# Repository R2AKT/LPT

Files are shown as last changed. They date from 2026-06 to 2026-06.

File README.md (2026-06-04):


License addendum - https://github.com/R2AKT/LPT/blob/main/Addendum.txt

# LPT
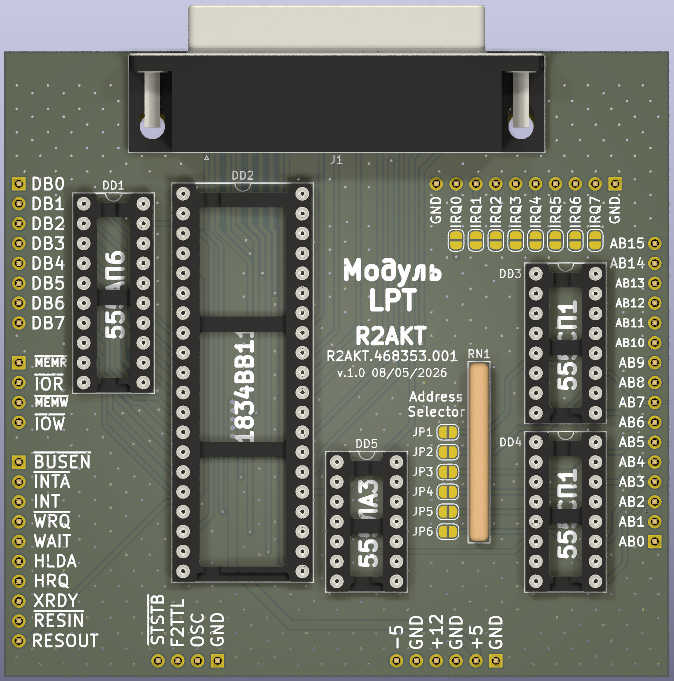
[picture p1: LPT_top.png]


LPT (Centrinics) module. For Mega-80 (Mega-580) DIY 8-bit micro-computer - https://github.com/R2AKT/Mega-80.

Based on 82C11 (1834VV11).

Status: In production. Not tested.

Модуль LPT (Centrinics). Для самодельной 8-битной микро-ЭВМ - https://github.com/R2AKT/Mega-80.

На основе 1834ВВ11 (82C11).

Статус: Изготовливается. Не тестировалась.

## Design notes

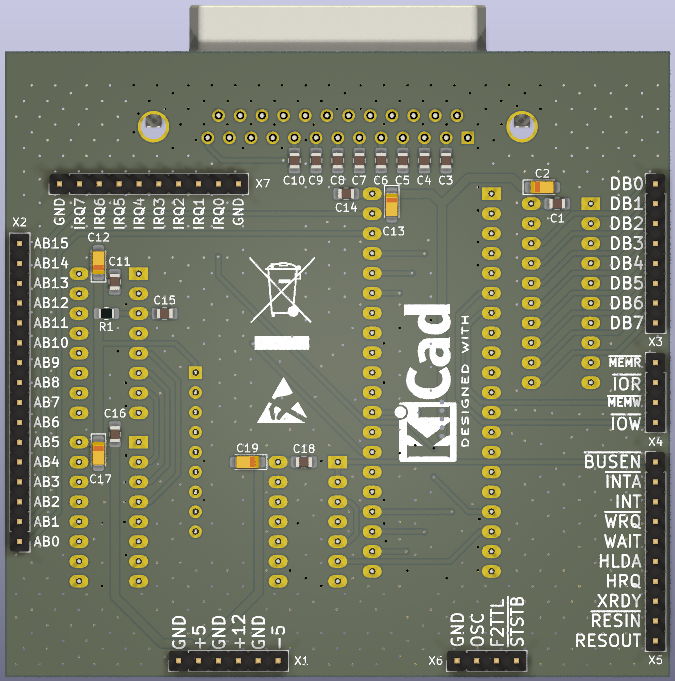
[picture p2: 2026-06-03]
LPT_btn.png

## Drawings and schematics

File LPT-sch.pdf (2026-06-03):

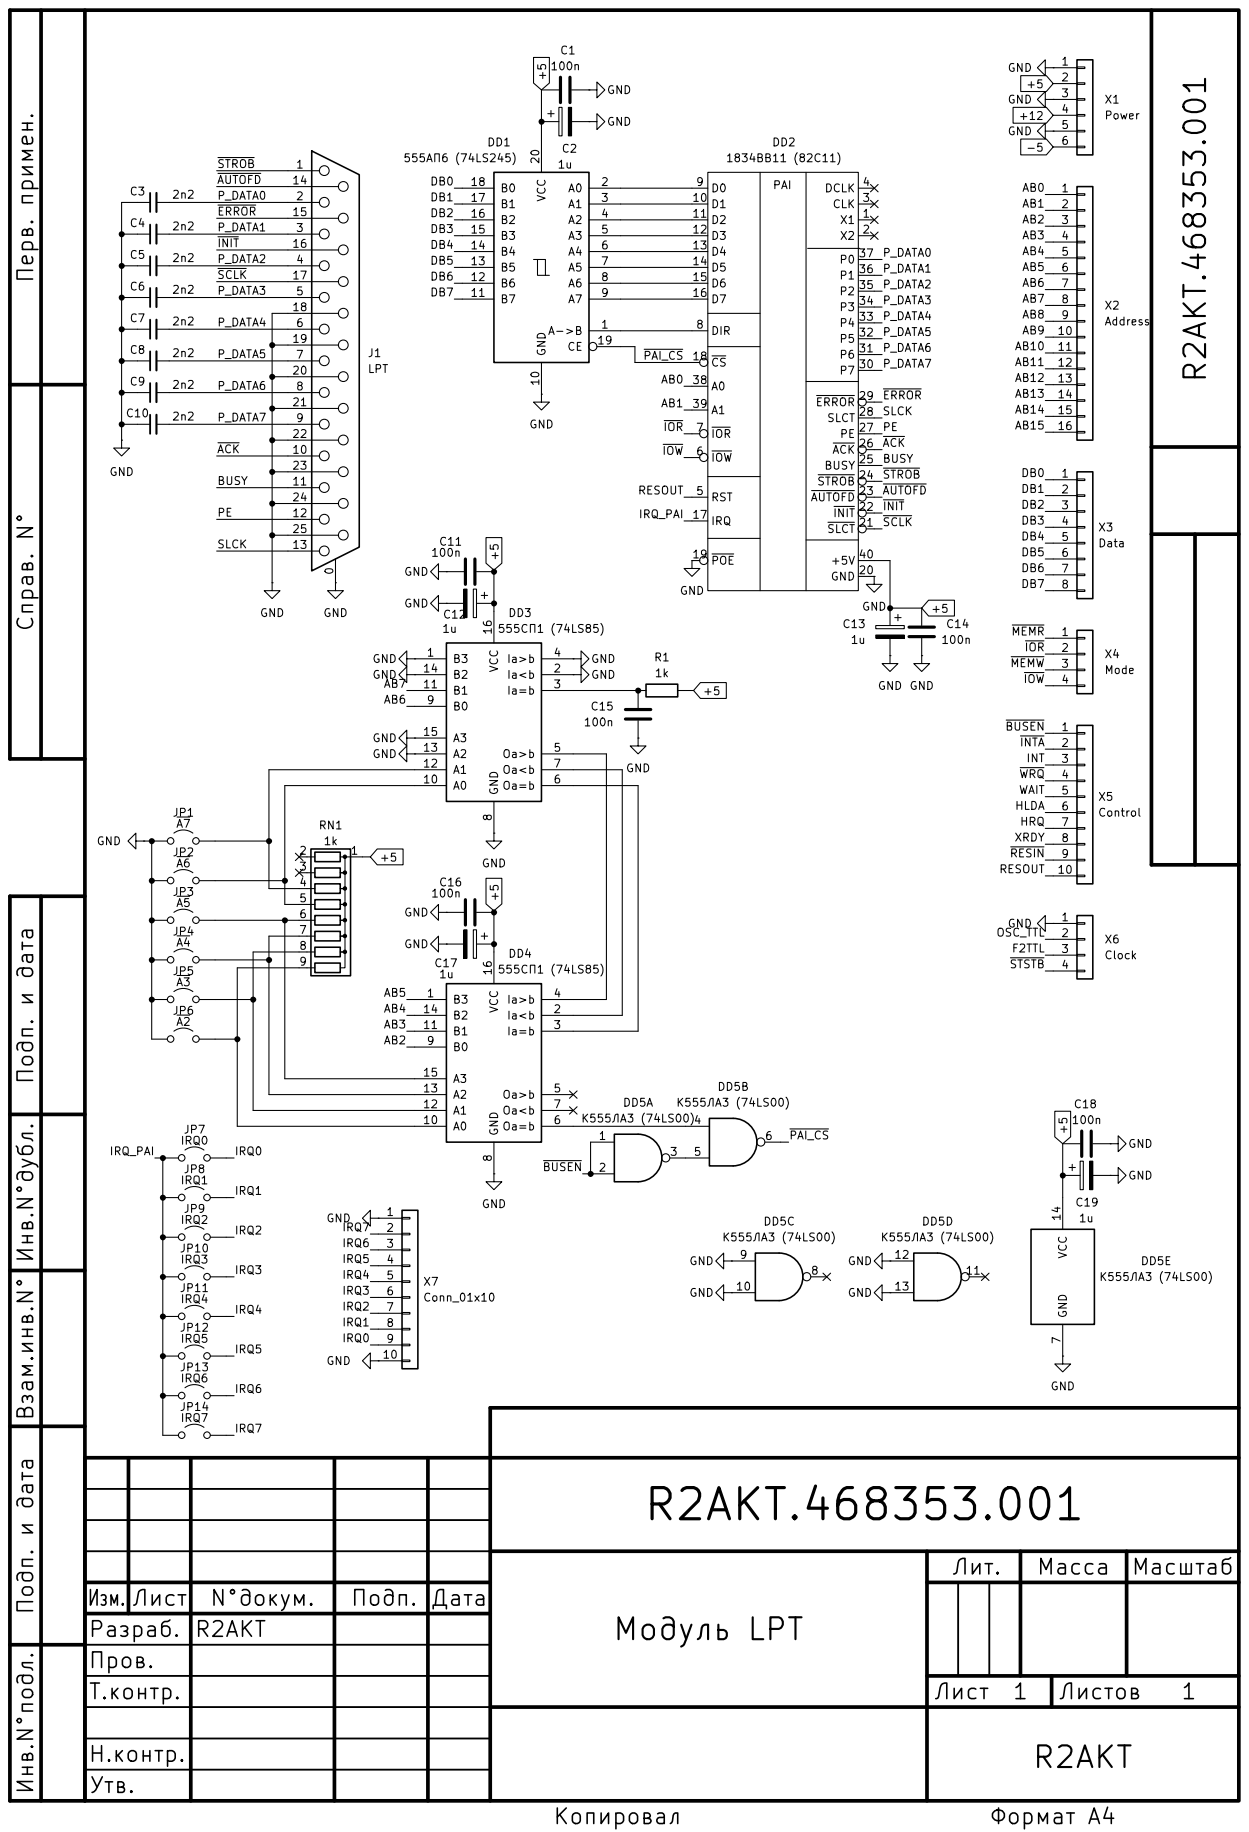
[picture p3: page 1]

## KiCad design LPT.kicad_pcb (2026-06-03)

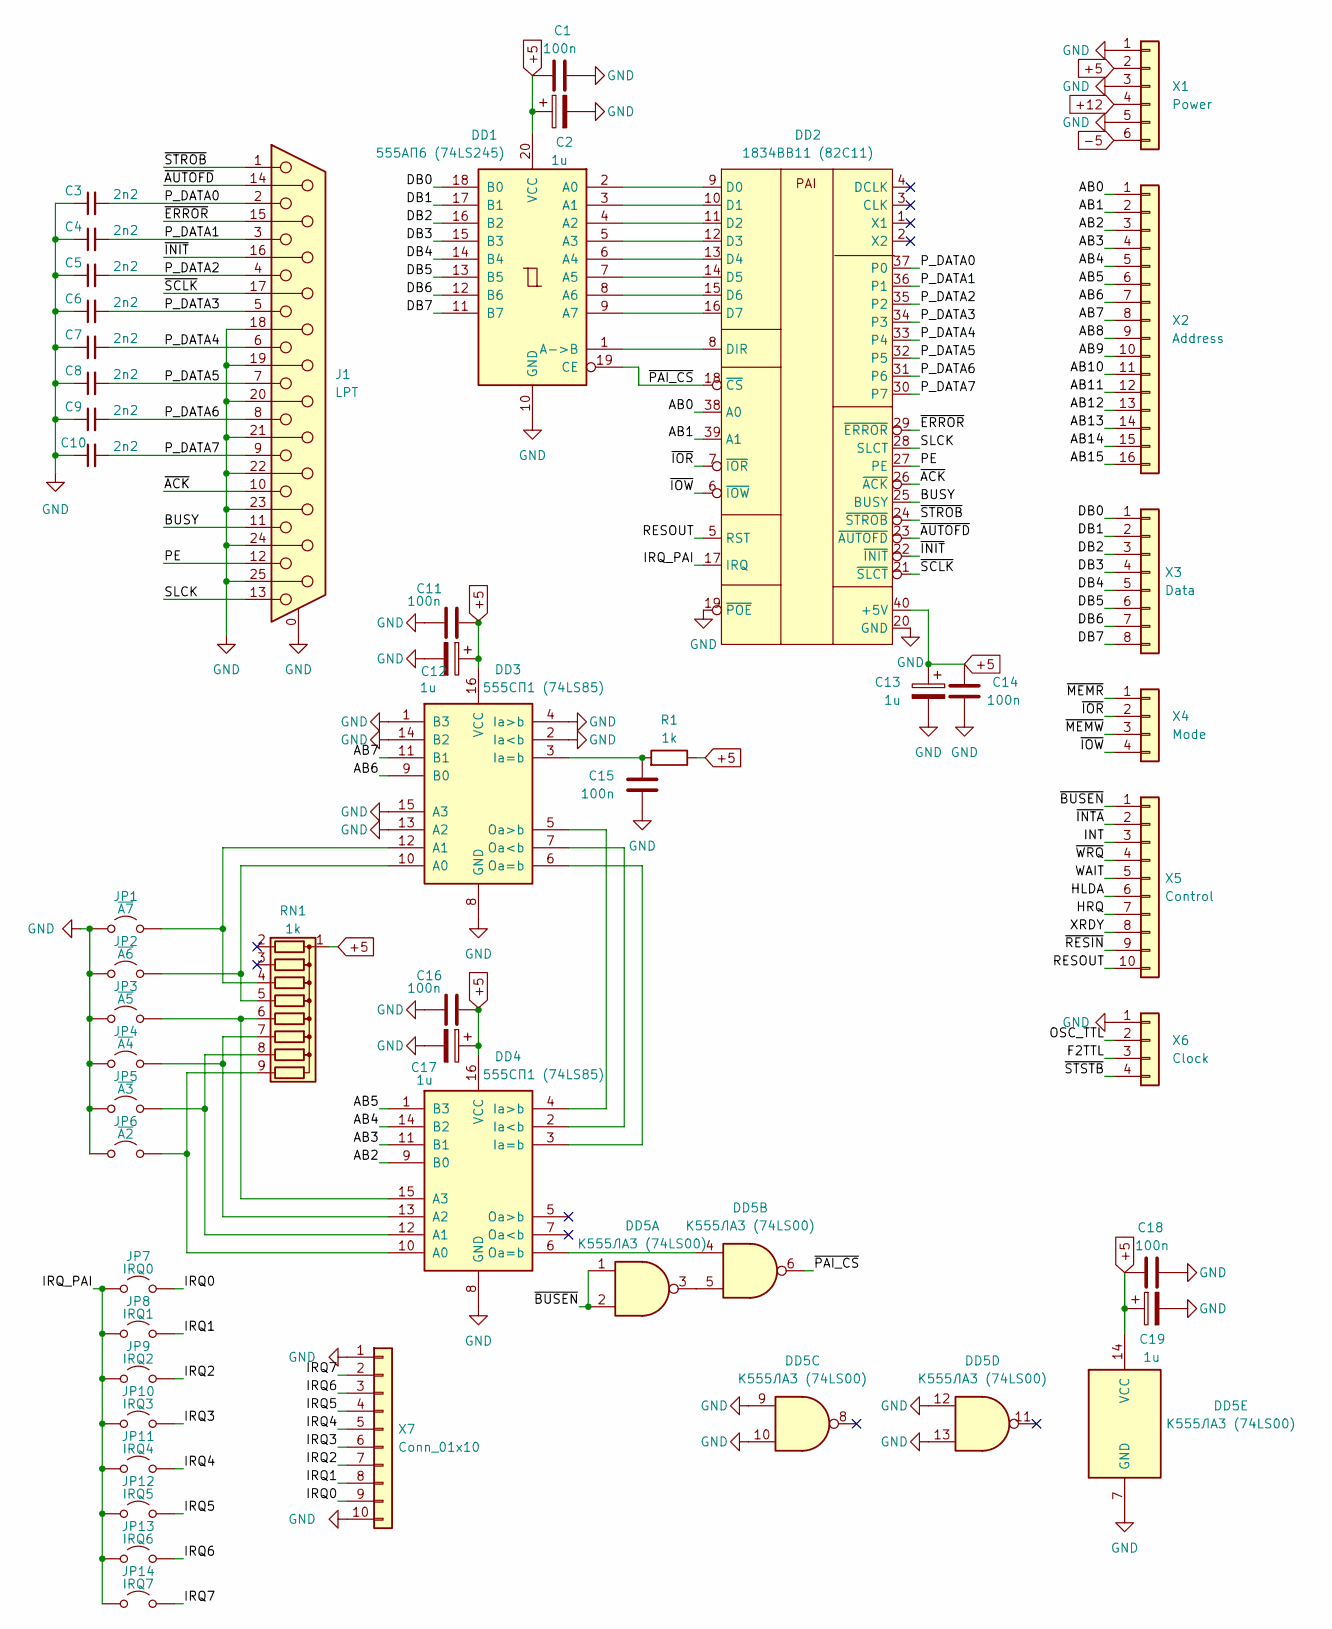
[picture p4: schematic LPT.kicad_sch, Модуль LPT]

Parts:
C1, C11, C14, C15, C16, C18: 100n; C_0805_2012Metric_Pad1.18x1.45mm_HandSolder
C2, C12, C13, C17, C19: 1u; CP_EIA-3216-18_Kemet-A_Pad1.58x1.35mm_HandSolder
C3, C4, C5, C6, C7, C8, C9, C10: 2n2; C_0805_2012Metric_Pad1.18x1.45mm_HandSolder
DD1: 555АП6 (74LS245); DIP-20_W7.62mm_Socket_LongPads
DD2: 1834ВВ11 (82C11); DIP-40_W15.24mm_Socket_LongPads
DD3, DD4: 555СП1 (74LS85); DIP-16_W7.62mm_Socket_LongPads
DD5: К555ЛА3 (74LS00); DIP-14_W7.62mm_Socket_LongPads
J1: LPT; DSUB-25_Female_Horizontal_P2.77x2.84mm_EdgePinOffset7.70mm_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
JP1: ~{A7}; SolderJumper-2_P1.3mm_Open_RoundedPad1.0x1.5mm
JP2: ~{A6}; SolderJumper-2_P1.3mm_Open_RoundedPad1.0x1.5mm
JP3: ~{A5}; SolderJumper-2_P1.3mm_Open_RoundedPad1.0x1.5mm
JP4: ~{A4}; SolderJumper-2_P1.3mm_Open_RoundedPad1.0x1.5mm
JP5: ~{A3}; SolderJumper-2_P1.3mm_Open_RoundedPad1.0x1.5mm
JP6: ~{A2}; SolderJumper-2_P1.3mm_Open_RoundedPad1.0x1.5mm
JP7: IRQ0; SolderJumper-2_P1.3mm_Open_RoundedPad1.0x1.5mm
JP8: IRQ1; SolderJumper-2_P1.3mm_Open_RoundedPad1.0x1.5mm
JP9: IRQ2; SolderJumper-2_P1.3mm_Open_RoundedPad1.0x1.5mm
JP10: IRQ3; SolderJumper-2_P1.3mm_Open_RoundedPad1.0x1.5mm
JP11: IRQ4; SolderJumper-2_P1.3mm_Open_RoundedPad1.0x1.5mm
JP12: IRQ5; SolderJumper-2_P1.3mm_Open_RoundedPad1.0x1.5mm
JP13: IRQ6; SolderJumper-2_P1.3mm_Open_RoundedPad1.0x1.5mm
JP14: IRQ7; SolderJumper-2_P1.3mm_Open_RoundedPad1.0x1.5mm
R1: 1k; R_0805_2012Metric_Pad1.20x1.40mm_HandSolder
RN1: 1k; R_Array_SIP9
X1: Power; PinHeader_1x06_P2.54mm_Vertical
X2: Address; PinHeader_1x16_P2.54mm_Vertical
X3: Data; PinHeader_1x08_P2.54mm_Vertical
X4: Mode; PinHeader_1x04_P2.54mm_Vertical
X5: Control; PinHeader_1x10_P2.54mm_Vertical
X6: Clock; PinHeader_1x04_P2.54mm_Vertical
X7: Conn_01x10; PinHeader_1x10_P2.54mm_Vertical

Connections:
+5: C1.1, C2.1, C11.1, C12.1, C13.1, C14.1, C16.1, C17.1, C18.1, C19.1, DD1.20 (VCC), DD2.40 (+5V), DD3.16 (VCC), DD4.16 (VCC), DD5.14 (VCC), R1.1, RN1.1 (common), X1.2
+12: X1.4
-5: X1.6
/AB0: DD2.38 (A0), X2.1
/AB1: DD2.39 (A1), X2.2
/AB2: DD4.9 (B0), X2.3
/AB3: DD4.11 (B1), X2.4
/AB4: DD4.14 (B2), X2.5
/AB5: DD4.1 (B3), X2.6
/AB6: DD3.9 (B0), X2.7
/AB7: DD3.11 (B1), X2.8
/AB8: X2.9
/AB9: X2.10
/AB10: X2.11
/AB11: X2.12
/AB12: X2.13
/AB13: X2.14
/AB14: X2.15
/AB15: X2.16
/BUSY: DD2.25 (BUSY), J1.11
/DB0: DD1.18 (B0), X3.1
/DB1: DD1.17 (B1), X3.2
/DB2: DD1.16 (B2), X3.3
/DB3: DD1.15 (B3), X3.4
/DB4: DD1.14 (B4), X3.5
/DB5: DD1.13 (B5), X3.6
/DB6: DD1.12 (B6), X3.7
/DB7: DD1.11 (B7), X3.8
/F2TTL: X6.3
/HLDA: X5.6
/HRQ: X5.7
/INT: X5.3
/IRQ0: JP7.2 (B), X7.9
/IRQ1: JP8.2 (B), X7.8
/IRQ2: JP9.2 (B), X7.7
/IRQ3: JP10.2 (B), X7.6
/IRQ4: JP11.2 (B), X7.5
/IRQ5: JP12.2 (B), X7.4
/IRQ6: JP13.2 (B), X7.3
/IRQ7: JP14.2 (B), X7.2
/IRQ_PAI: DD2.17 (IRQ), JP7.1 (A), JP8.1 (A), JP9.1 (A), JP10.1 (A), JP11.1 (A), JP12.1 (A), JP13.1 (A), JP14.1 (A)
/OSC_TTL: X6.2
/PE: DD2.27 (PE), J1.12
/P_DATA0: C3.2, DD2.37 (P0), J1.2
/P_DATA1: C4.2, DD2.36 (P1), J1.3
/P_DATA2: C5.2, DD2.35 (P2), J1.4
/P_DATA3: C6.2, DD2.34 (P3), J1.5
/P_DATA4: C7.2, DD2.33 (P4), J1.6
/P_DATA5: C8.2, DD2.32 (P5), J1.7
/P_DATA6: C9.2, DD2.31 (P6), J1.8
/P_DATA7: C10.2, DD2.30 (P7), J1.9
/RESOUT: DD2.5 (RST), X5.10
/SLCK: DD2.28 (SLCT), J1.13
/WAIT: X5.5
/XRDY: X5.8
/~ACK: DD2.26 (~ACK), J1.10
/~AUTOFD: DD2.23 (~AUTOFD), J1.14
/~BUSEN: DD5.1, DD5.2, X5.1
/~ERROR: DD2.29 (~ERROR), J1.15
/~INIT: DD2.22 (~INIT), J1.16
/~INTA: X5.2
/~IOR: DD2.7 (~IOR), X4.2
/~IOW: DD2.6 (~IOW), X4.4
/~MEMR: X4.1
/~MEMW: X4.3
/~PAI_CS: DD1.19 (CE), DD2.18 (~CS), DD5.6
/~RESIN: X5.9
/~SCLK: DD2.21 (~SLCT), J1.17
/~STROB: DD2.24 (~STROB), J1.1
/~STSTB: X6.4
/~WRQ: X5.4
GND: C1.2, C2.2, C3.1, C4.1, C5.1, C6.1, C7.1, C8.1, C9.1, C10.1, C11.2, C12.2, C13.2, C14.2, C15.2, C16.2, C17.2, C18.2, C19.2, DD1.10 (GND), DD2.19 (~POE), DD2.20 (GND), DD3.1 (B3), DD3.2 (Ia<b), DD3.4 (Ia>b), DD3.8 (GND), DD3.13 (A2), DD3.14 (B2), DD3.15 (A3), DD4.8 (GND), DD5.7 (GND), DD5.9, DD5.10, DD5.12, DD5.13, J1.0 (PAD), J1.18, J1.19, J1.20, J1.21, J1.22, J1.23, J1.24, J1.25, JP1.1 (A), JP2.1 (A), JP3.1 (A), JP4.1 (A), JP5.1 (A), JP6.1 (A), X1.1, X1.3, X1.5, X6.1, X7.1, X7.10
unnamed: DD1.2 (A0), DD2.9 (D0)
unnamed: DD1.3 (A1), DD2.10 (D1)
unnamed: DD1.4 (A2), DD2.11 (D2)
unnamed: DD1.5 (A3), DD2.12 (D3)
unnamed: DD1.6 (A4), DD2.13 (D4)
unnamed: DD1.7 (A5), DD2.14 (D5)
unnamed: DD1.8 (A6), DD2.15 (D6)
unnamed: DD1.9 (A7), DD2.16 (D7)
unnamed: DD1.1 (A->B), DD2.8 (DIR)
unnamed: DD3.10 (A0), JP2.2 (B), RN1.5 (R4)
unnamed: DD3.12 (A1), JP1.2 (B), RN1.4 (R3)
unnamed: C15.1, DD3.3 (Ia=b), R1.2
unnamed: DD3.7 (Oa<b), DD4.2 (Ia<b)
unnamed: DD3.6 (Oa=b), DD4.3 (Ia=b)
unnamed: DD3.5 (Oa>b), DD4.4 (Ia>b)
unnamed: DD4.10 (A0), JP6.2 (B), RN1.9 (R8)
unnamed: DD4.12 (A1), JP5.2 (B), RN1.8 (R7)
unnamed: DD4.13 (A2), JP4.2 (B), RN1.7 (R6)
unnamed: DD4.15 (A3), JP3.2 (B), RN1.6 (R5)
unnamed: DD4.6 (Oa=b), DD5.4
unnamed: DD5.3, DD5.5

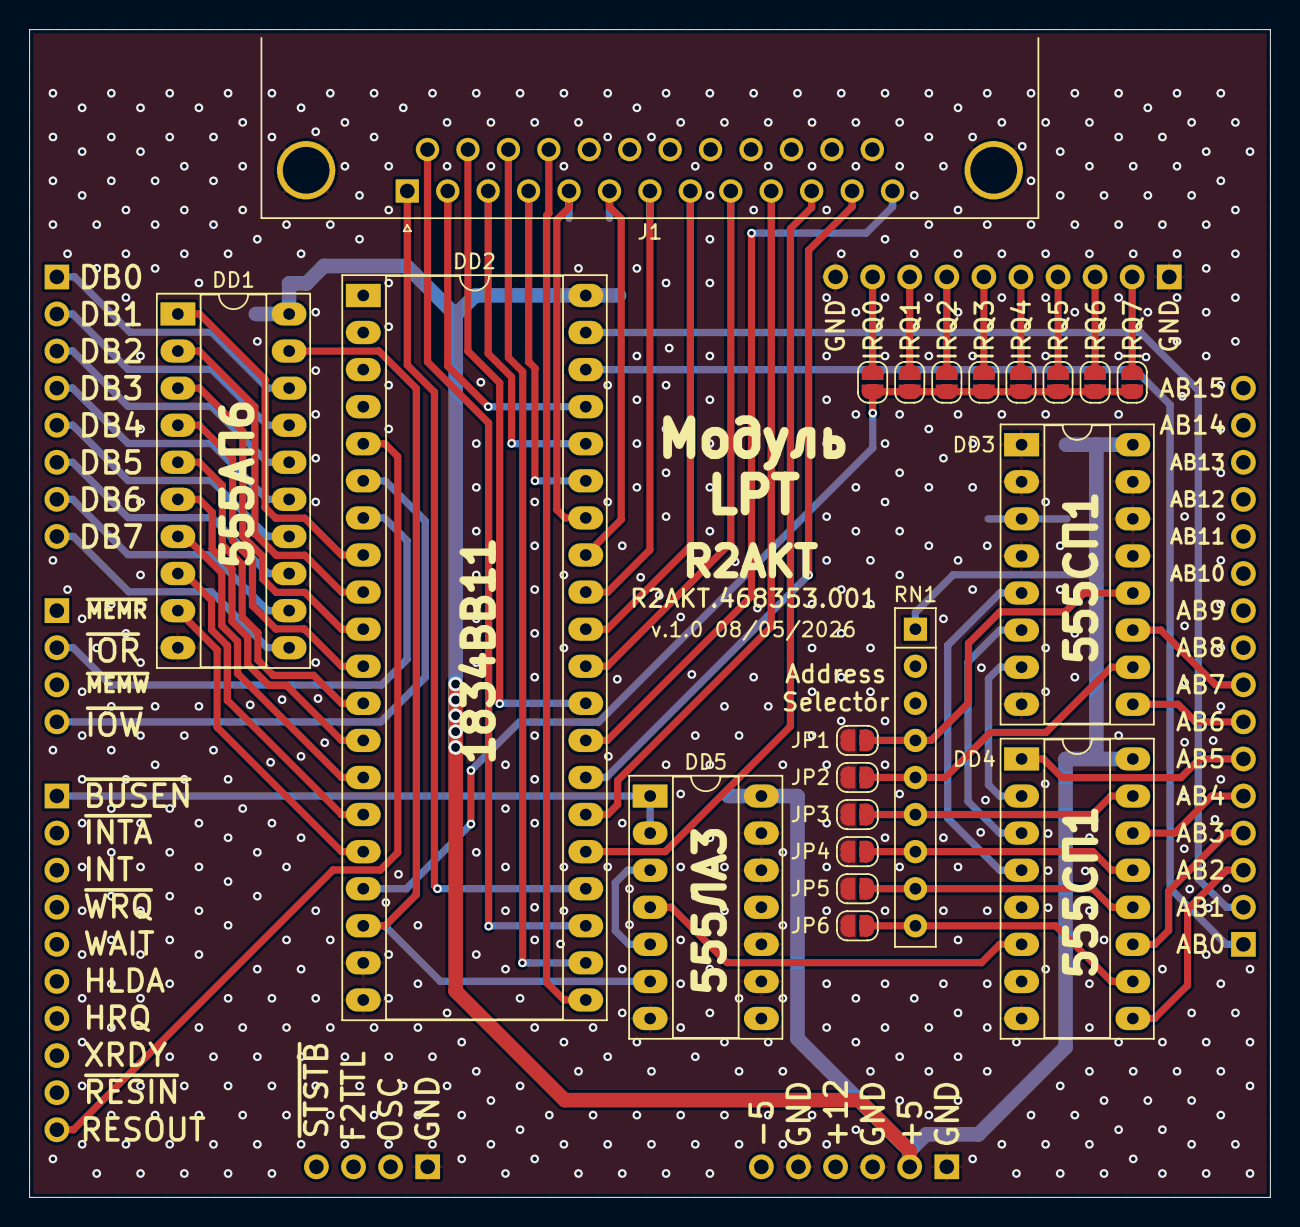
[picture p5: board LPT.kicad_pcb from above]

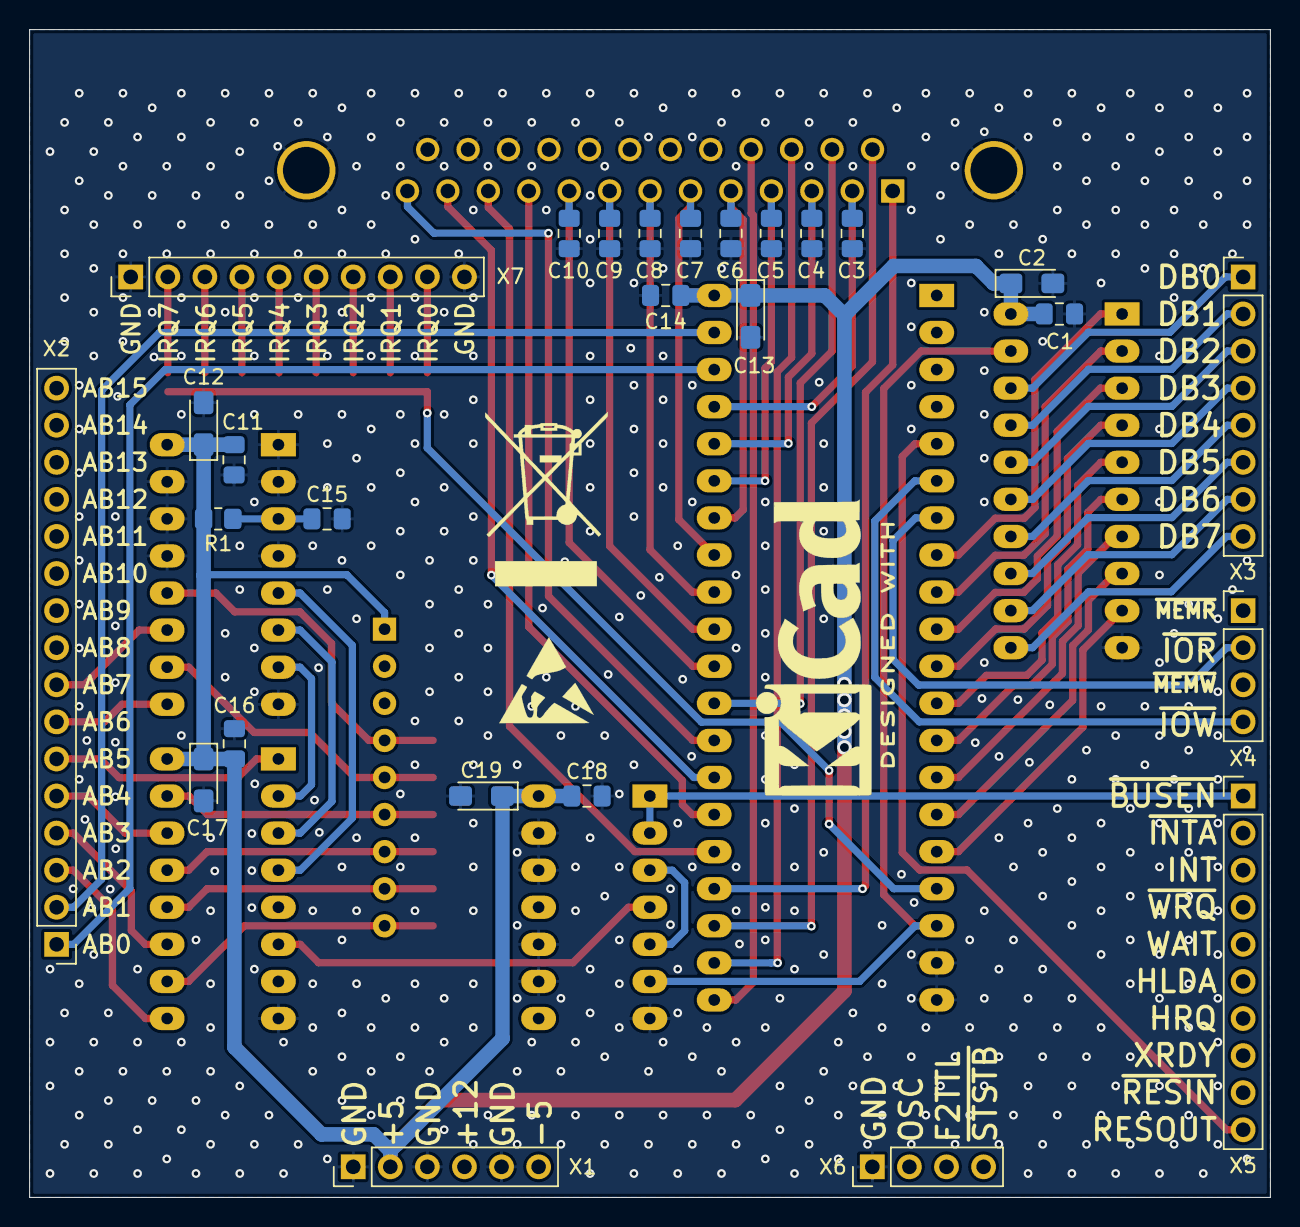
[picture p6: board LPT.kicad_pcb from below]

Board: 2 copper layers, 85.0 x 80.0 mm, 48 parts (27 on the bottom side), 70 nets.

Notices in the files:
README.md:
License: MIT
